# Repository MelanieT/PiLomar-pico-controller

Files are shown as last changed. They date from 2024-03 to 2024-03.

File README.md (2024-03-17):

# Pilomar Pico firmware

## Firmware for driving two standard stepper drivers

You can use the board files in hardware/ to have the board fabbed, or you can use a stock pico and wire up the stepper drivers according to the schematic.

The pico will appear as a USB network device and two serial ports, the first of which is the console, which is also available on a JST-SM connector on the board.

It serves a REST API as described in the PilomarAPI.yaml file, which is maintained in the jPiLomar project.

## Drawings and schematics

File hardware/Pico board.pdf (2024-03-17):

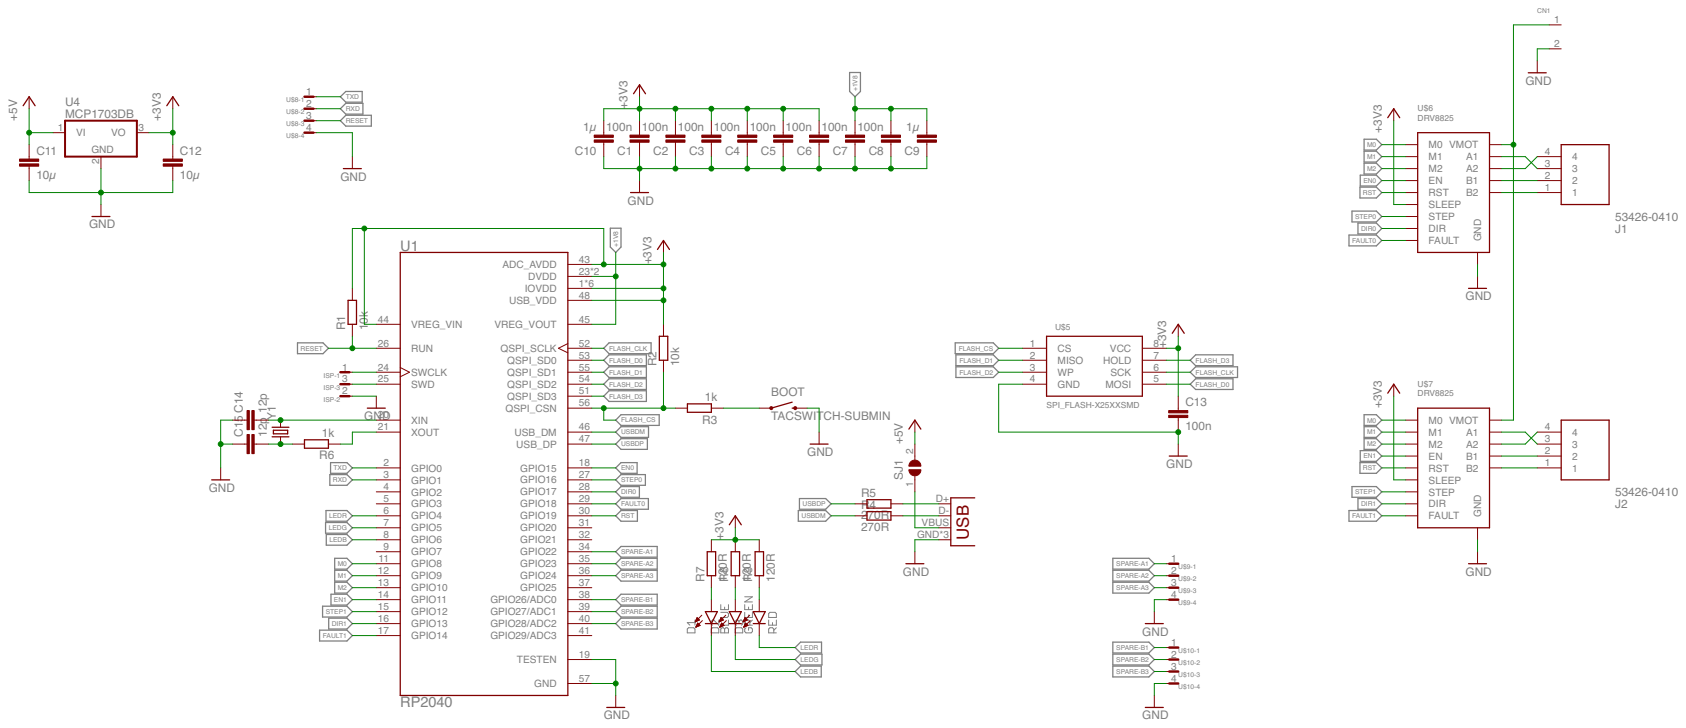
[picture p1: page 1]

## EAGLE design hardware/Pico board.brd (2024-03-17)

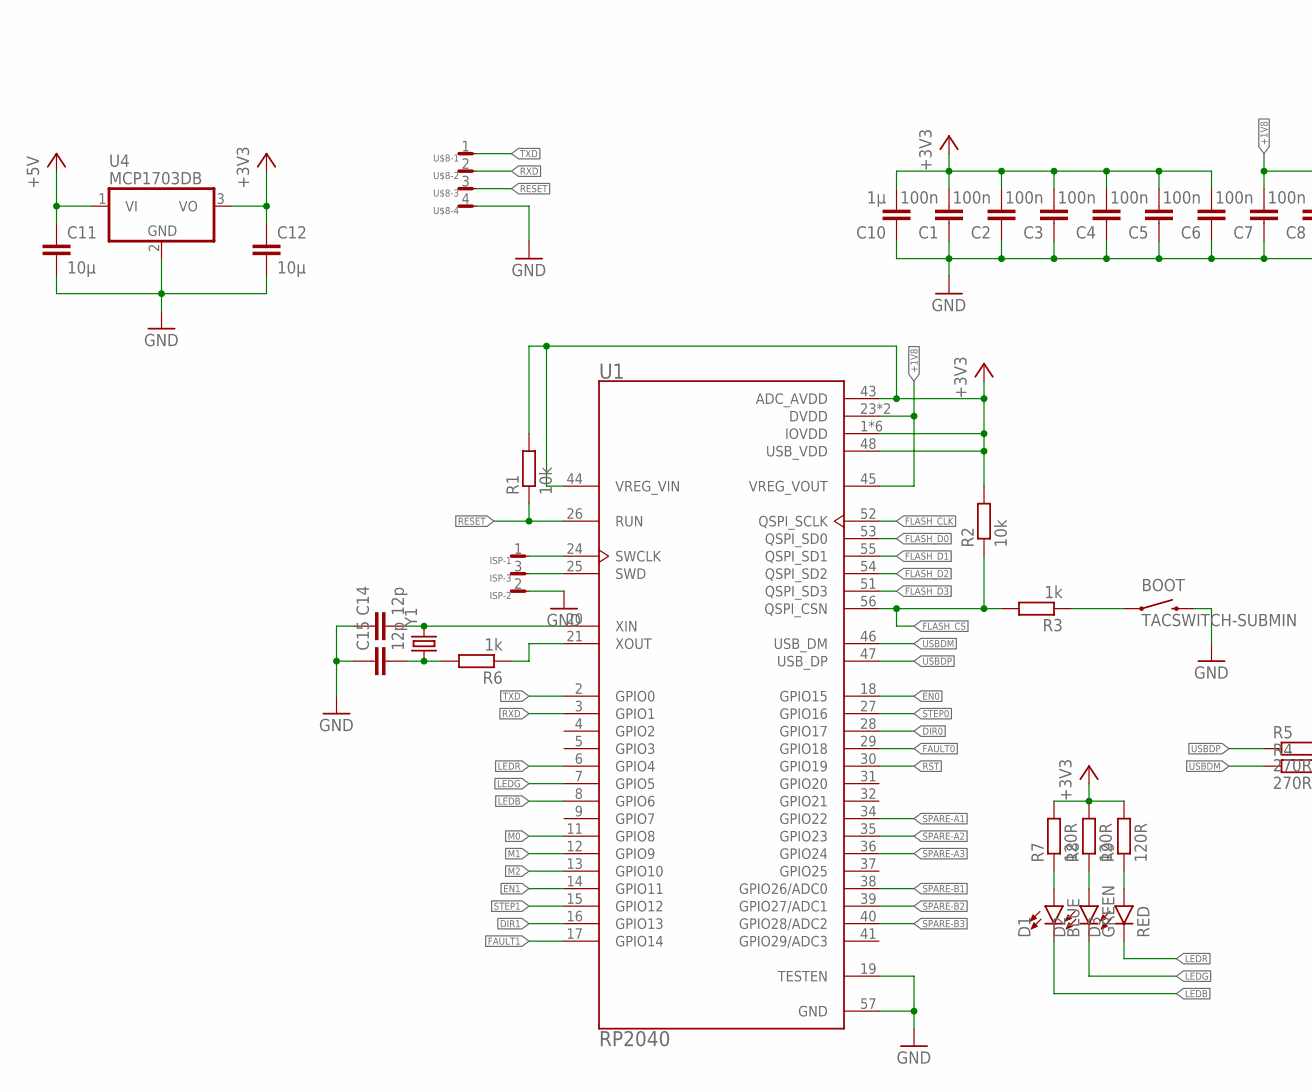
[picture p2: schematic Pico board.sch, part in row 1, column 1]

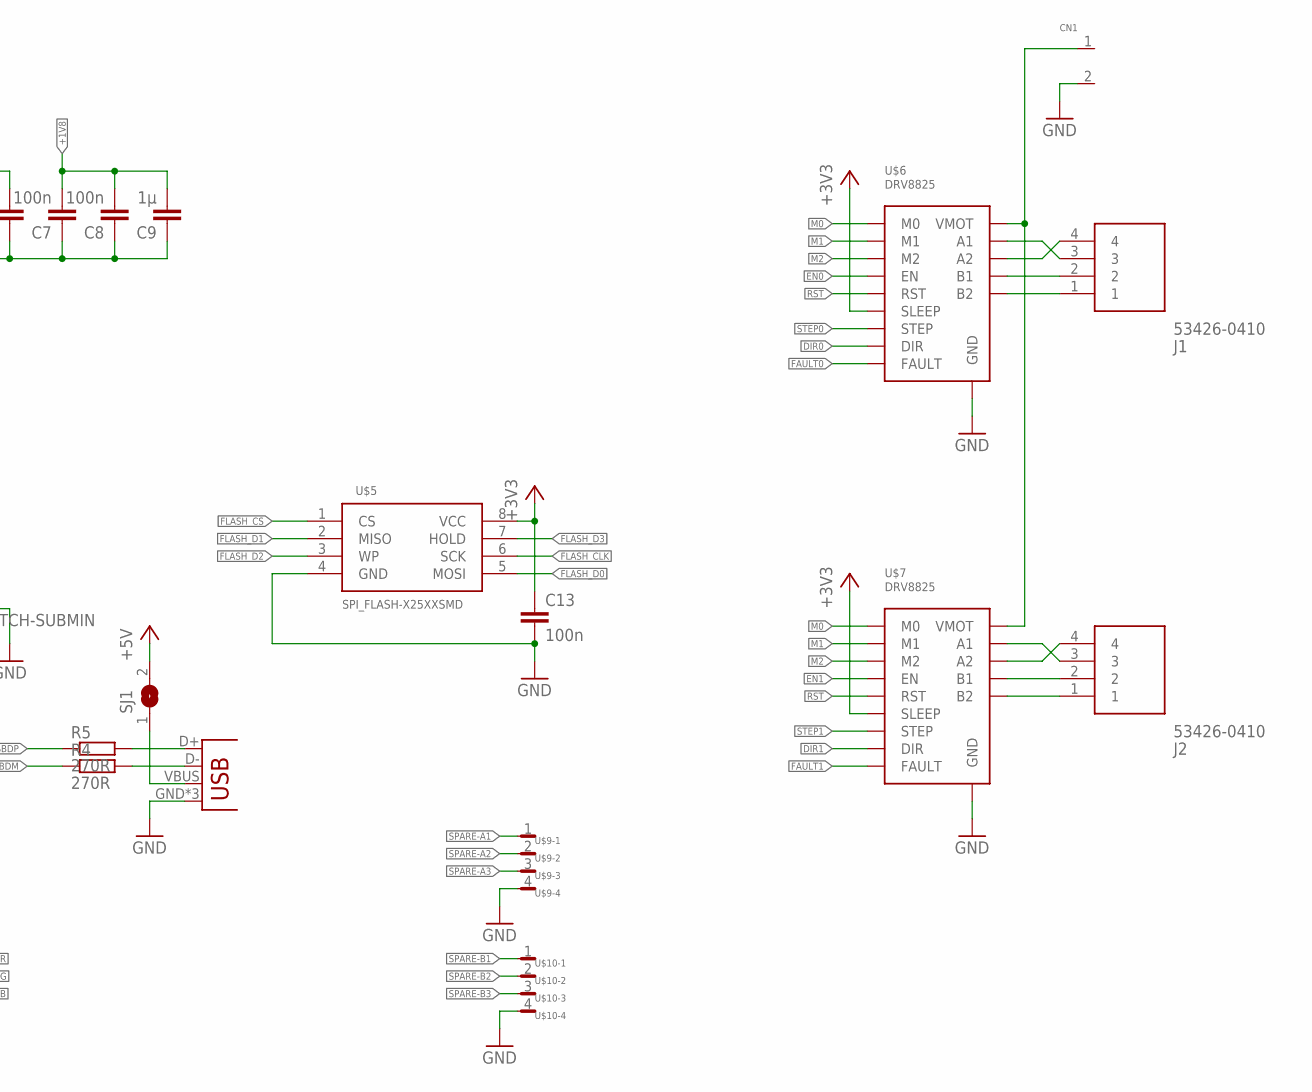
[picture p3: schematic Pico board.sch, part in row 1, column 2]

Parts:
BOOT: TACSWITCH-SUBMIN; TACSWITCH_SUBMIN
C1, C2, C3, C4, C5, C6, C7, C8, C13: 100n; C0402K
C9, C10: 1µ; C0603K
C11, C12: 10µ; C1206K
C14, C15: 12p; C0402K
CN1: 2PIN_SCREW_TRM; CONN2P
D1: BLUE; LED-0603
D2: GREEN; LED-0603
D3: RED; LED-0603
ISP: SM03B-SRSS-TB
J1, J2: 53426-0410; SHDRRA4W55P0X250_1X4_1240X1150
JP1: USB-MICROB
R1, R2: 10k; R0402
R3, R6: 1k; R0402
R4, R5: 270R; R0402
R7, R8, R9: 120R; R0402
SJ1: SJ
U1: RP2040; QFN40P700X700X90-57N
U4: MCP1703DB; SOT223
U$5: SPI_FLASH-X25XXSMD; SO08
U$6, U$7: DRV8825; POLOLU
U$8, U$9, U$10: SM04B-SRSS-TB
Y1: CRYSTAL5X3; CRYSTAL-SMD-5X3

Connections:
+1V8: C7.2, C8.2, C9.2, U1.23 (DVDD), U1.45 (VREG_VOUT), U1.50 (DVDD)
+3V3: C1.2, C2.2, C3.2, C4.2, C5.2, C6.2, C10.2, C12.1, C13.1, R1.2, R2.2, R7.2, R8.2, R9.2, U1.1 (IOVDD), U1.10 (IOVDD), U1.22 (IOVDD), U1.33 (IOVDD), U1.42 (IOVDD), U1.43 (ADC_AVDD), U1.44 (VREG_VIN), U1.48 (USB_VDD), U1.49 (IOVDD), U4.3 (VO), U$5.8 (VCC), U$6.SLEEP, U$7.SLEEP
+5V: C11.1, SJ1.2, U4.1 (VI)
DIR0: U1.28 (GPIO17), U$6.DIR
DIR1: U1.16 (GPIO13), U$7.DIR
EN0: U1.18 (GPIO15), U$6.ENABLE (EN)
EN1: U1.14 (GPIO11), U$7.ENABLE (EN)
FAULT0: U1.29 (GPIO18), U$6.FAULT
FAULT1: U1.17 (GPIO14), U$7.FAULT
FLASH_CLK: U1.52 (QSPI_SCLK), U$5.6 (SCK)
FLASH_CS: R2.1, R3.2, U1.56 (QSPI_CSN), U$5.1 (CS)
FLASH_D0: U1.53 (QSPI_SD0), U$5.5 (MOSI)
FLASH_D1: U1.55 (QSPI_SD1), U$5.2 (MISO)
FLASH_D2: U1.54 (QSPI_SD2), U$5.3 (WP)
FLASH_D3: U1.51 (QSPI_SD3), U$5.7 (HOLD)
GND: BOOT.-2 (2), C1.1, C2.1, C3.1, C4.1, C5.1, C6.1, C7.1, C8.1, C9.1, C10.1, C11.2, C12.2, C13.2, C14.1, C15.1, CN1.2, ISP.2, JP1.GND, JP1.MT1 (GND), JP1.MT2 (GND), U1.19 (TESTEN), U1.57 (GND), U4.2 (GND), U$5.4 (GND), U$6.GND@1 (GND), U$6.GND@2 (GND), U$7.GND@1 (GND), U$7.GND@2 (GND), U$8.4, U$9.4, U$10.4
LEDB: D1.C, U1.8 (GPIO6)
LEDG: D2.C, U1.7 (GPIO5)
LEDR: D3.C, U1.6 (GPIO4)
M0: U1.11 (GPIO8), U$6.M0, U$7.M0
M1: U1.12 (GPIO9), U$6.M1, U$7.M1
M2: U1.13 (GPIO10), U$6.M2, U$7.M2
unnamed: J1.3, U$6.A1
unnamed: JP1.D+, R5.2
unnamed: JP1.D-, R4.2
unnamed: J1.4, U$6.A2
unnamed: BOOT.-1 (1), R3.1
unnamed: J2.2, U$7.B1
unnamed: J2.1, U$7.B2
unnamed: J2.3, U$7.A1
unnamed: J2.4, U$7.A2
unnamed: JP1.VBUS, SJ1.1
unnamed: ISP.1, U1.24 (SWCLK)
unnamed: ISP.3, U1.25 (SWD)
unnamed: C15.2, R6.2, Y1.1
unnamed: R6.1, U1.21 (XOUT)
unnamed: C14.2, U1.20 (XIN), Y1.3 (2)
unnamed: J1.2, U$6.B1
unnamed: J1.1, U$6.B2
unnamed: D1.A, R7.1
unnamed: D2.A, R8.1
unnamed: CN1.1, U$6.VMOT, U$7.VMOT
unnamed: D3.A, R9.1
RESET: R1.1, U1.26 (RUN), U$8.3
RST: U1.30 (GPIO19), U$6.RESET (RST), U$7.RESET (RST)
RXD: U1.3 (GPIO1), U$8.2
SPARE-A1: U1.34 (GPIO22), U$9.1
SPARE-A2: U1.35 (GPIO23), U$9.2
SPARE-A3: U1.36 (GPIO24), U$9.3
SPARE-B1: U1.38 (GPIO26/ADC0), U$10.1
SPARE-B2: U1.39 (GPIO27/ADC1), U$10.2
SPARE-B3: U1.40 (GPIO28/ADC2), U$10.3
STEP0: U1.27 (GPIO16), U$6.STEP
STEP1: U1.15 (GPIO12), U$7.STEP
TXD: U1.2 (GPIO0), U$8.1
USBDM: R4.1, U1.46 (USB_DM)
USBDP: R5.1, U1.47 (USB_DP)

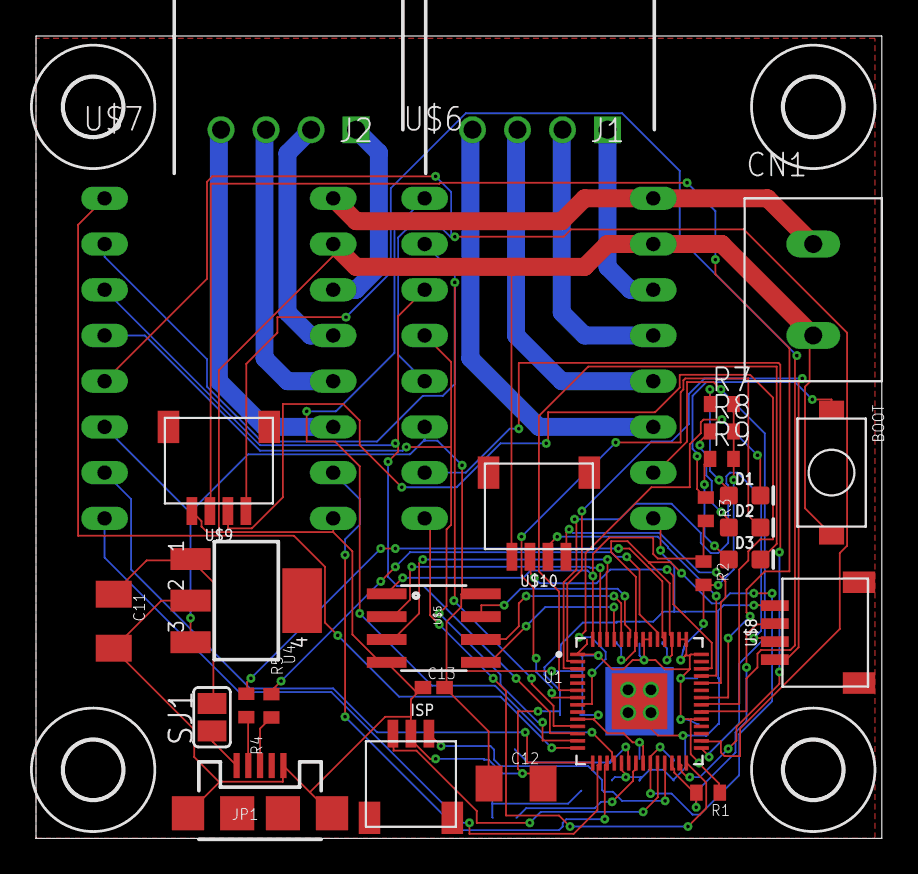
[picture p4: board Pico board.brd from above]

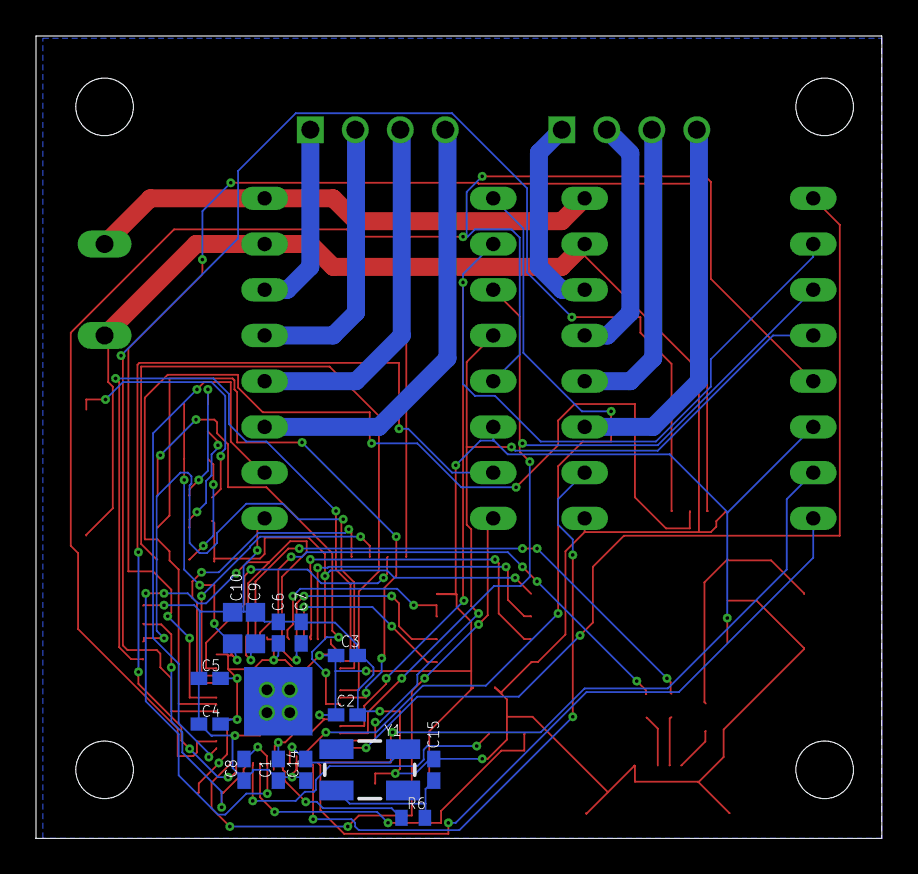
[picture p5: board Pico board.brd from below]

Board: 2 copper layers, 47.0 x 44.6 mm, 47 parts (14 on the bottom side), 57 nets.

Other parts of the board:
U$1, U$2, U$3, U$4: 3,2

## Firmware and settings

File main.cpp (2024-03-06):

// SPDX-FileCopyrightText: 2024 Melanie Thielker & Leonie Gaertner
// SPDX-License-Identifier: BSD-3-Clause

#include <cstdio>
#include <pico/time.h>
#include <hardware/gpio.h>
#include <vector>
#include <pico/stdlib.h>
#include <hardware/flash.h>
#include "pico/stdio.h"
#include "Motor.h"
#include "tusb.h"
#include "tusb_lwip_glue.h"
#include "webserver/WebServer-lwip.h"
#include "webserver/ApiServer.h"
#include "UrlMapper.h"
#include "nlohmann/json.hpp"

#define MODE_DOOR 0
#define MODE_CAMERA 1
#define MODE MODE_CAMERA

#define LED_BLUE  4
#define LED_GREEN 5
#define LED_RED   6
#define STEP_M0   8
#define STEP_M1   9
#define STEP_M2   10
#define RST       19
#define EN0       15
#define STEP0     16
#define DIR0      17
#define VCC0      18
#define EN1       11
#define STEP1     12
#define DIR1      13
#define VCC1      14

#define SPARE_A1  22
#define SPARE_A2  23
#define SPARE_A3  24

#define SPARE_B1  26
#define SPARE_B2  27
#define SPARE_B3  28

#define AZIMUTH_MAX_SPEED 8000
#define AZIMUTH_STEPS_PER_REVOLUTION 384000
#define AZIMUTH_MAX_STEPS 384000 //373334

#define ELEVATION_MAX_SPEED 8000
#define ELEVATION_STEPS_PER_REVOLUTION 384000
#define ELEVATION_MAX_STEPS 120000
#define ELEVATION_ZERO_POINT 22500

#define DOOR_MAX_STEPS 2125
#define DOOR_MAX_SPEED 400

using namespace nlohmann;

uint8_t macaddr[6];

uint8_t tud_network_mac_address[6];

Motor *stepper0;
Motor *stepper1;

WebServerLwip webserver;

class PilomarApi
{
public:
    static void Init()
    {
        UrlMapper::AddMapping("GET", "/info", &info);
        UrlMapper::AddMapping("POST", "/move", &move);
    }
private:
#if MODE == MODE_DOOR
    static void move(const HttpRequest& request, HttpResponse& response)
    {
        auto payload = json::parse(request.body(), nullptr, false);
        if (payload.is_discarded())
        {
            response.setStatusCode(HttpStatus::Code::BadRequest);
            return;
        }

        if (stepper0->isRunning() || stepper1->isRunning())
        {
            response.setStatusCode(HttpStatus::Code::PreconditionFailed);
            return;
        }

        auto mode = payload.value<std::string>("mode", "move");

        if (mode == "move")
        {
            int position = payload.value("position", -1);
            int speed = payload.value("speed", DOOR_MAX_SPEED);

            if (position < 0 || position > DOOR_MAX_STEPS || speed < 10 || speed > DOOR_MAX_SPEED)
            {
                response.setStatusCode(HttpStatus::Code::BadRequest);
                return;
            }
            stepper0->runToTarget(speed, position);
            stepper1->runToTarget(speed, position);
        }
        else if (mode == "learn")
        {
            stepper0->setCurrentPosition(DOOR_MAX_STEPS);
            stepper1->setCurrentPosition(DOOR_MAX_STEPS);
            stepper0->runToTarget(DOOR_MAX_SPEED, 0);
            stepper1->runToTarget(DOOR_MAX_SPEED, 0);
        }
        else
        {
            response.setStatusCode(HttpStatus::Code::BadRequest);
            return;
        }

        response.setBody(
                json{
                    {"result", "ok"}
                }.dump()
            );
    }
#elif MODE == MODE_CAMERA
#pragma clang diagnostic push
#pragma ide diagnostic ignored "bugprone-branch-clone"
    static void move(const HttpRequest& request, HttpResponse& response)
    {
        auto payload = json::parse(request.body(), nullptr, false);
        if (payload.is_discarded())
        {
            response.setStatusCode(HttpStatus::Code::BadRequest);
            return;
        }

        auto motor = payload.value<std::string>("motor", "");
        Motor *m = nullptr;
        if (motor == "azimuth")
            m = stepper1;
        else if (motor == "elevation")
            m = stepper0;

        if (!m)
        {
            response.setStatusCode(HttpStatus::Code::BadRequest);
            return;
        }

//        if (m->isRunning())
//        {
//            response.setStatusCode(HttpStatus::Code::PreconditionFailed);
//            return;
//        }

        int maxSpeed = motor == "elevation" ? ELEVATION_MAX_SPEED : AZIMUTH_MAX_SPEED;
        int maxSteps = motor == "elevation" ? ELEVATION_MAX_STEPS : AZIMUTH_MAX_STEPS;

        int position = payload.value("position", -1);
        auto speed = payload.value<double>("speed", (double)maxSpeed);

        if (position < 0 || position > maxSteps || speed < 0.0001 || speed > maxSpeed)
        {
            response.setStatusCode(HttpStatus::Code::BadRequest);
            return;
        }

        m->runToTarget(speed, position);

        response.setBody(
            json{
                {"result", "ok"}
            }.dump()
        );
    }
#pragma clang diagnostic pop
#endif
    static void info(const HttpRequest& request, HttpResponse& response)
    {
        response.setBody(
            json{
#if MODE == MODE_DOOR
                {"type", "door"},
                {"max_steps", DOOR_MAX_STEPS},
                {"max_speed", DOOR_MAX_SPEED},
                {"position_left", stepper0->getCurrentPosition()},
                {"position_right", stepper1->getCurrentPosition()},
                {"closed_position", 0},
                {"open_position", DOOR_MAX_STEPS}
#elif MODE == MODE_CAMERA
                {"type", "camera"},
                {"azimuth", stepper1->getCurrentPosition()},
                {"elevation", stepper0->getCurrentPosition()},
                {"max_elevation", ELEVATION_MAX_STEPS},
                {"max_azimuth", AZIMUTH_MAX_STEPS},
                {"max_speed_azimuth", AZIMUTH_MAX_SPEED},
                {"max_speed_elevation", ELEVATION_MAX_SPEED}
#endif
            }.dump()
        );
    }
};

void usbd_serial_init(void)
{
    uint8_t id[8];

    flash_get_unique_id(id);

    tud_network_mac_address[0] = 0xb8;
    tud_network_mac_address[1] = 0x27;
    tud_network_mac_address[2] = 0xeb;
    tud_network_mac_address[3] = id[5];
    tud_network_mac_address[4] = id[6];
    tud_network_mac_address[5] = id[7];
}

#pragma clang diagnostic push
#pragma ide diagnostic ignored "EndlessLoop"
int main()
{
    usbd_serial_init();
    tusb_init();
    stdio_init_all();

    init_lwip();

    wait_for_netif_is_up();

    dhcpd_init();

    webserver.Init();
    PilomarApi::Init();

    std::vector<uint> gpios_out = {4, 5, 6, 8, 9, 10, 11, 12, 13, 14, 15, 16, 17, 18, 19};
    std::vector<uint> gpios_in = {};

    for (auto p: gpios_out)
    {
        gpio_init(p);
        gpio_set_dir(p, true);
        gpio_put(p, true);
    }

    for (auto p: gpios_in)
    {
        gpio_init(p);
        gpio_set_dir(p, false);
    }

    gpio_put(LED_GREEN, false);

    // Reset stepper drivers
    gpio_put(RST, false);
    sleep_ms(10);
    gpio_put(RST, true);

    // Set step ouputs to low
    gpio_put(STEP0, false);
    gpio_put(STEP1, false);

#if MODE == MODE_CAMERA
    gpio_put(STEP_M0, true);
    gpio_put(STEP_M1, true);
    gpio_put(STEP_M2, false);
#elif MODE == MODE_DOOR
    gpio_put(STEP_M0, false);
    gpio_put(STEP_M1, false);
    gpio_put(STEP_M2, false);
#endif


    gpio_put(DIR0, true); // false is up
    gpio_put(DIR1, true); // false is clockwise

//    Motor stepper((Pins){STEP0, DIR0, EN0, SPARE_B3, false, true}, ELEVATION_STEPS_PER_REVOLUTION, ELEVATION_MAX_STEPS);
//    Motor stepper0((Pins){STEP0, DIR0, EN0, -1, false, false}, AZIMUTH_STEPS_PER_REVOLUTION, AZIMUTH_MAX_STEPS);
//    Motor stepper1((Pins){STEP1, DIR1, EN1, -1, false, false}, AZIMUTH_STEPS_PER_REVOLUTION, AZIMUTH_MAX_STEPS);
//

#if MODE == MODE_DOOR
    stepper0 = new Motor((Pins){STEP0, DIR0, EN0}, (Options){.autoPowerOff = true, .reverse = true, .microsteps = 1}, DOOR_MAX_STEPS, DOOR_MAX_STEPS);
    stepper1 = new Motor((Pins){STEP1, DIR1, EN1}, (Options){.autoPowerOff = true, .reverse = true, .microsteps = 1}, DOOR_MAX_STEPS, DOOR_MAX_STEPS);
#elif MODE == MODE_CAMERA
    stepper0 = new Motor((Pins){STEP0, DIR0, EN0}, (Options){.reverse = true, .endstop = SPARE_B3, .dirToEndstop = false}, ELEVATION_STEPS_PER_REVOLUTION, ELEVATION_MAX_STEPS);
    stepper1 = new Motor((Pins){STEP1, DIR1, EN1}, (Options){}, AZIMUTH_STEPS_PER_REVOLUTION, AZIMUTH_MAX_STEPS);
#endif

    uint64_t ticks = 0;

    while (true)
    {
//        if (tud_cdc_n_available(1))
//        {
//            char c = tud_cdc_n_read_char(1);
//            tud_cdc_n_write_char(1, c);
//            tud_cdc_n_write_flush(1);
//        }
        ++ticks;

        if (!(ticks % 5000))
        {
//            printf("Blink\n");
            gpio_put(LED_RED, !gpio_get_out_level(LED_RED));
        }

        tud_task();
        service_traffic();
        webserver.ProcessMessages(ApiServer::RequestHandler);

        sleep_us(100);
    }
}
#pragma clang diagnostic pop

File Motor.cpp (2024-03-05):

// SPDX-FileCopyrightText: 2024 Melanie Thielker & Leonie Gaertner
// SPDX-License-Identifier: BSD-3-Clause

// This is the highest wrap resulting in an integral frequency, it represents 1/2 full step per second
#define MAX_WRAP 62500.0

#define MIN_HZ 10

#define SPEED_STEP (31 * options.microsteps)
#define SPEED_STEP_PULSES (5 * options.microsteps)

#define DIV_MIN ((0x01 << 4) + 0x0)

#include <cstdio>
#include <hardware/pwm.h>
#include <algorithm>
#include <hardware/regs/intctrl.h>
#include <hardware/irq.h>
#include <hardware/gpio.h>
#include "Motor.h"

bool Motor::initialized = false;
std::list<Motor *> Motor::instances;

Motor::Motor(Pins pins, Options options, int microStepsPerRevolution, int maxSteps)
{
    this->pins = pins;
    this->options = options;

    this->microStepsPerRevolution = microStepsPerRevolution;
    this->maxSteps = maxSteps;

//    printf("Pins: step %d dir %d enable %d\r\n", this->pins.step, this->pins.dir, this->pins.enable);
//    printf("Max steps %d\r\n", maxSteps);

    gpio_set_function(pins.step, GPIO_FUNC_SIO);
    gpio_set_dir(pins.step, true);
    gpio_put(pins.step, false);
    gpio_disable_pulls(pins.step);

    gpio_set_function(pins.dir, GPIO_FUNC_SIO);
    gpio_set_dir(pins.dir, true);
    gpio_put(pins.dir, false);
    gpio_disable_pulls(pins.dir);

    gpio_set_function(pins.enable, GPIO_FUNC_SIO);
    gpio_set_dir(pins.enable, true);
    gpio_put(pins.enable, true);
    gpio_disable_pulls(pins.enable);

    if (options.endstop != -1)
    {
        gpio_set_function(options.endstop, GPIO_FUNC_SIO);
        gpio_set_dir(options.endstop, false);
        gpio_pull_up(options.endstop);
    }

    sliceNumber = pwm_gpio_to_slice_num(pins.step);

    if (std::find_if(Motor::instances.begin(), Motor::instances.end(),
                     [this](const Motor *motor) {return motor->sliceNumber == this->sliceNumber;}) != Motor::instances.end())
    {
        printf("Duplicate slices are not supported\r\n");
        return; // Should throw here but that is disabled on Pico
    }

    Motor::instances.emplace_back(this);

    if (!initialized)
    {
        irq_set_exclusive_handler(PWM_IRQ_WRAP, &Motor::interruptHandler);
        irq_set_enabled(PWM_IRQ_WRAP, true);

        initialized = true;
    }
    pwm_set_irq_enabled(sliceNumber, true);

    pwm_set_clkdiv_mode(sliceNumber, PWM_DIV_FREE_RUNNING);
    pwm_set_clkdiv_int_frac(sliceNumber, 250, 0);

    if (!homed)
        home();

    add_repeating_timer_ms(1000, alarmHandler, this, &timerData);

    while (!homed)
        sleep_ms(10);
}

Motor::~Motor()
{
    Motor::instances.remove(this);
}

void Motor::setPwmFreq(float freq) const {
    uint32_t clock = 125000000;
    auto div = (uint32_t)((double)(clock << 4) / freq / MAX_WRAP);
    if (div < DIV_MIN) {
        div = DIV_MIN;
    }
    if (div > 254 * 16)
        div = 256 * 16;
    auto top = (uint32_t)(((double)(clock << 4) / div / freq) - 1);
    float out = (float)(clock << 4) / (float)div / (float)(top + 1);

    // Some code useful for debugging this. Uncomment as needed
//    printf("Freq = %f, ",         freq);
//    printf("Top = %ld, ",         top);
//    printf("Div = %.2f, ", (float)div/16);
//    printf("Out = %f\n",          out);

    pwm_set_wrap(sliceNumber, top);
    pwm_set_chan_level(sliceNumber, PWM_CHAN_A, div << 4);
    pwm_set_clkdiv_int_frac(sliceNumber, div >> 4, div & 0x0f);
    pwm_set_enabled(sliceNumber, true);
}

void Motor::interruptHandler()
{
    for (int slice = 0; slice < 8; slice++)
    {
        if (pwm_get_irq_status_mask() & (1 << slice))
        {
            auto it = std::find_if(Motor::instances.begin(), Motor::instances.end(),
                                   [slice](Motor *motor) {return motor->sliceNumber == slice;});
            if (it != Motor::instances.end())
            {
                (*it)->handleSpecificInterrupt();
            }
            pwm_clear_irq(slice);
        }
    }
}

void Motor::handleSpecificInterrupt()
{
    if (state != Running)
    {
//        if (!gpio_get(pins.endstop))
//        {
//            pwm_set_enabled(sliceNumber, false);
//            stepsToGo = 0;
//            homed = true;
//            position = 0;
//            state = Stopped;
//
//            return;
//        }

        position++;

        if (state == MovingOffEndstop)
        {
            if (gpio_get(options.endstop))
            {
                state = Homing;
                setDirection(options.dirToEndstop);
            }
        }
        if (state == Homing)
        {
            if (!gpio_get(options.endstop))
            {
                state = BackingUp;
                setDirection(!options.dirToEndstop);
                position = -125 * options.microsteps;
            }
        }
        if (state == BackingUp)
        {
            if (position >= 0)
            {
                pwm_set_enabled(sliceNumber, false);
                state = Stopped;
                homed = true;
                if (options.callback != nullptr)
                {
                    if (options.callback(options.userData))
                        disableMotor();
                }
                else
                {
                    if (options.autoPowerOff)
                        disableMotor();
                }
            }
        }
        return;
    }

    if (options.endstop != -1)
    {
        if (!gpio_get(options.endstop))
        {
            // HALP! Hit endstop in normal run
            pwm_set_enabled(sliceNumber, false);
            state = Stopped;
            position = 0;
        }
    }

    performStep();

    if (stepsToGo)
    {
        if (!--stepsToGo)
            motorSpeedStep();
    }
}

bool Motor::alarmHandler(repeating_timer_t *timer)
{
    return ((Motor *)timer->user_data)->handleSpecificAlarm();
}

#pragma clang diagnostic push
#pragma ide diagnostic ignored "readability-convert-member-functions-to-static"
#pragma ide diagnostic ignored "readability-make-member-function-const"
bool Motor::handleSpecificAlarm()
{
    if (gpio_get_out_level(pins.step))
    {
        gpio_put(pins.step, false);

        if (!performStep())
            return false;

        if (stepsToGo)
        {
            if (!--stepsToGo)
            {
                motorSpeedStep();
                return false;
            }
        }
    }
    else
    {
        gpio_put(pins.step, true);
    }

    return true;
}
#pragma clang diagnostic pop

void Motor::home()
{
    if (options.endstop == -1)
    {
        homed = true;
        if (!options.autoPowerOff && options.callback == nullptr)
            enableMotor();
        return;
    }

    setPwmMode();

    if (!gpio_get(options.endstop) && state != BackingUp)
    {
//        printf("Move off endstop\n");
        setDirection(!options.dirToEndstop);
        state = MovingOffEndstop;
        setPwmFreq(250.0f * (float)options.microsteps);

        enableMotor();

        return;
    }
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

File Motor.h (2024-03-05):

// SPDX-FileCopyrightText: 2024 Melanie Thielker & Leonie Gaertner
// SPDX-License-Identifier: BSD-3-Clause

#ifndef PILOMAR_MOTOR_H
#define PILOMAR_MOTOR_H

#include <pico/time.h>
#include "list"

struct Pins
{
    int step;
    int dir;
    int enable;
};

struct Options
{
    bool autoPowerOff = false;
    void *userData = nullptr;
    bool (*callback)(void *userData) = nullptr;
    bool reverse = false;
    int endstop = -1;
    bool dirToEndstop = false;
    int microsteps = 8;
};

class Motor
{
public:
    Motor(Pins motor, Options options, int microStepsPerRevolution, int maxSteps);
    ~Motor();

    void setOptions(Options options);
    Options getOptions();
    void home();
    void runToTarget(double targetSpeed, int target);
    bool isRunning();
    void disableMotor() const;
    void setCurrentPosition(int position);
    [[nodiscard]] int getCurrentPosition() const;

protected:
    unsigned sliceNumber;

private:
    enum State
    {
        Stopped,
        Running,
        Homing,
        MovingOffEndstop,
        BackingUp
    };

    volatile State state = Stopped;         // State of motor
    volatile double speed = 0;              // Current speed
    volatile bool direction = false;        // Current direction
    volatile bool homed = false;            // true if motor has been homed
    volatile int position = 0;              // Current absolute position
    volatile int stepsToGo = 0;             // Motor steps to go on this plan step

    struct
    {
        int steps;
        double speed;
        bool direction;
        int expectedPosition;
    } plan[1024] = {};
    int step = 0;

    int microStepsPerRevolution;
    int maxSteps;
    Pins pins{};
    Options options;

    static std::list<Motor *> instances;

    static bool initialized;
    repeating_timer_t timerData{};

    void setPwmMode() const;
    void setGpioMode() const;
    void enableMotor() const;
    void setDirection(bool forward);
    [[nodiscard]] int motorSpeedStepDeltaSteps(int delta) const;
    void motorSpeedStep();
    void runStepper(double newSpeed, bool newDirection);
    void setPwmFreq(float freq) const;
    bool performStep();
    static void interruptHandler();
    void handleSpecificInterrupt();

    static bool alarmHandler(repeating_timer_t *t);
    bool handleSpecificAlarm();

};


#endif //PILOMAR_MOTOR_H

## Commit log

2024-03-06 Tolerate double slashes in URL. Add new fields to camera info
2024-03-07 Assemble received packets until one full http message is received
2024-03-17 Add hardware files
    [Pico board.brd, Pico board.sch]
2024-03-25 Switch to our own registered USB vid/pid

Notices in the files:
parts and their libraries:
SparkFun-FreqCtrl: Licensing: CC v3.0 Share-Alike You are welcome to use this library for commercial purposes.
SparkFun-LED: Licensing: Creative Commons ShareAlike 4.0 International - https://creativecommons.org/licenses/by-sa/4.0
